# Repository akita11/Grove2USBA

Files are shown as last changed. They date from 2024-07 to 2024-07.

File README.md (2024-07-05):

# Grove2USBA

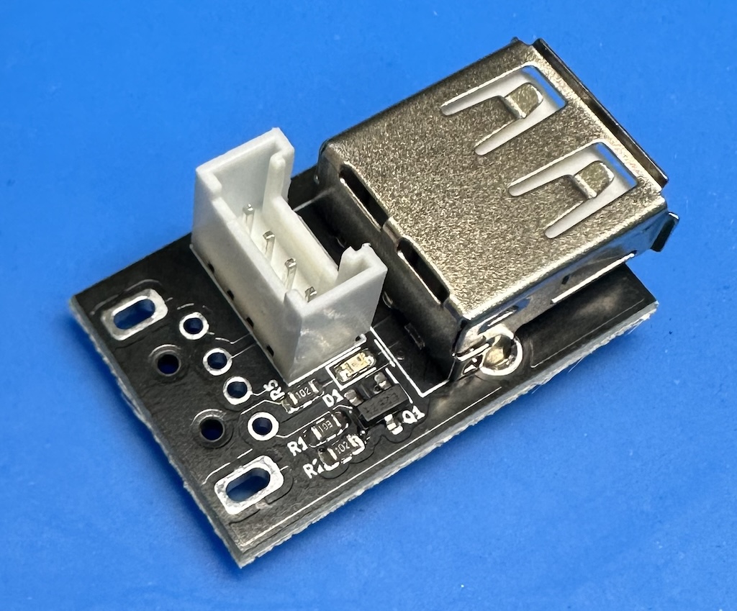
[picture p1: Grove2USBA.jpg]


Grove端子から電源(+5V)をUSB-Aコネクタ（ソケット）への給電をGrove端子の信号線で制御することができます。

## 使い方

Grove端子をM5Stack等に接続し、給電したい機器をUSB-Aコネクタに接続します。Grove端子の信号線（初期状態では"A"(2番)）を"L"にすると給電され、"H"（または開放）にすると給電されません。

給電したい機器への電力はGrove端子から受けますので、供給側の電力供給が不足する場合は、[「M5Stack USB TypeC2Grove外部電源供給ユニット」](https://www.switch-science.com/products/8453)等をつかって電源を強化してください。

## 設定の変更

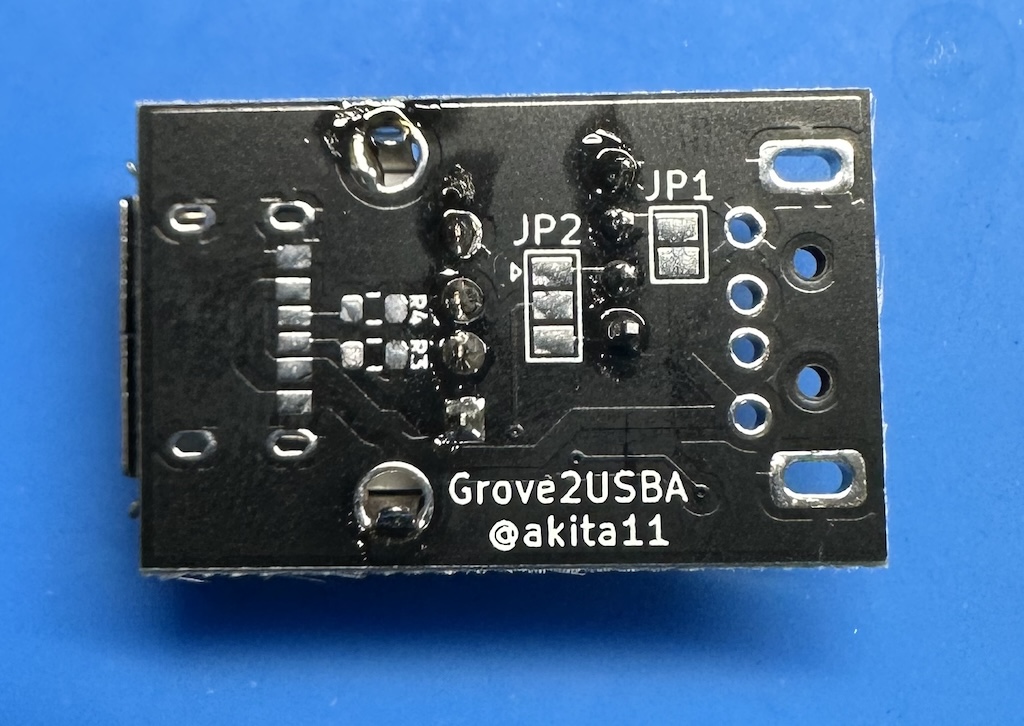
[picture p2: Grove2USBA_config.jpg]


コネクタへの給電制御をGrove端子の2本の信号線のどちらで行うかを切り替えることができます。

- A(2番): JP2を中央-△マークのある側をショート（初期状態）
- B(1番): JP2を中央-△マークのない側をショート（※中央-△マークのある側のパターンをカットしてください）

## 使い方（オプション）

給電のためのUSB-Aプラグ、またはUSB-Cコネクタを追加でとりつけ、そちらから給電することができます。
これらを使う場合は、JP1をカット（初期状態はショート）することで、Grove端子からの+5V給電を切ることができます。

- USB-Aプラグ: [秋月電子・USB-4AM103AS](https://akizukidenshi.com/catalog/g/g102236/)等
- USB-Cコネクタ: [秋月電子・UJC-HP-3-SMT-TR](https://akizukidenshi.com/catalog/g/g116438/)等＋5.1kΩチップ抵抗(0603/1608)x2個

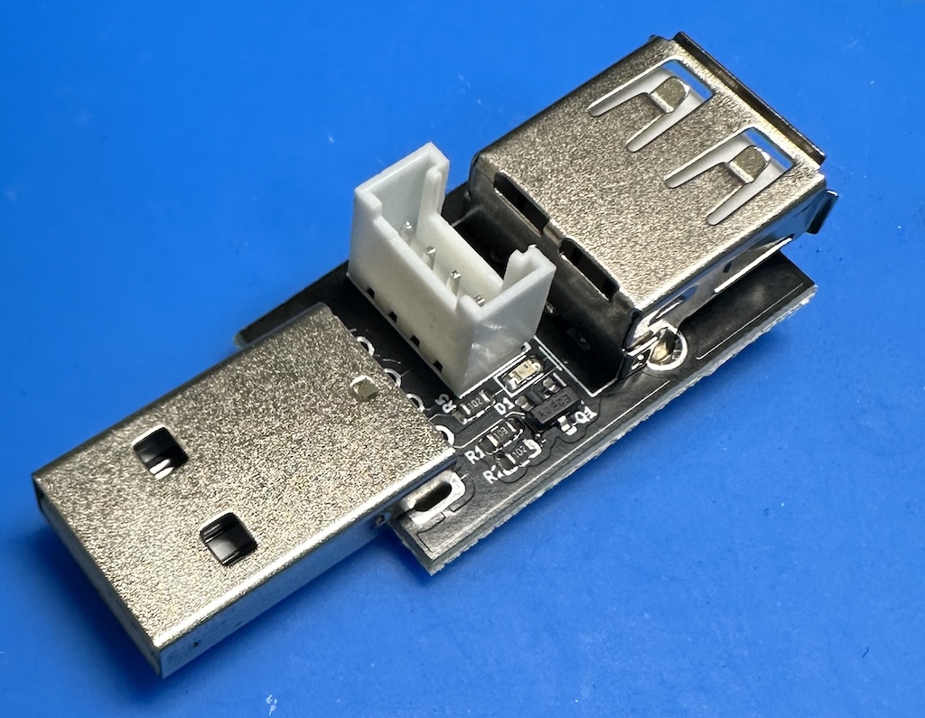
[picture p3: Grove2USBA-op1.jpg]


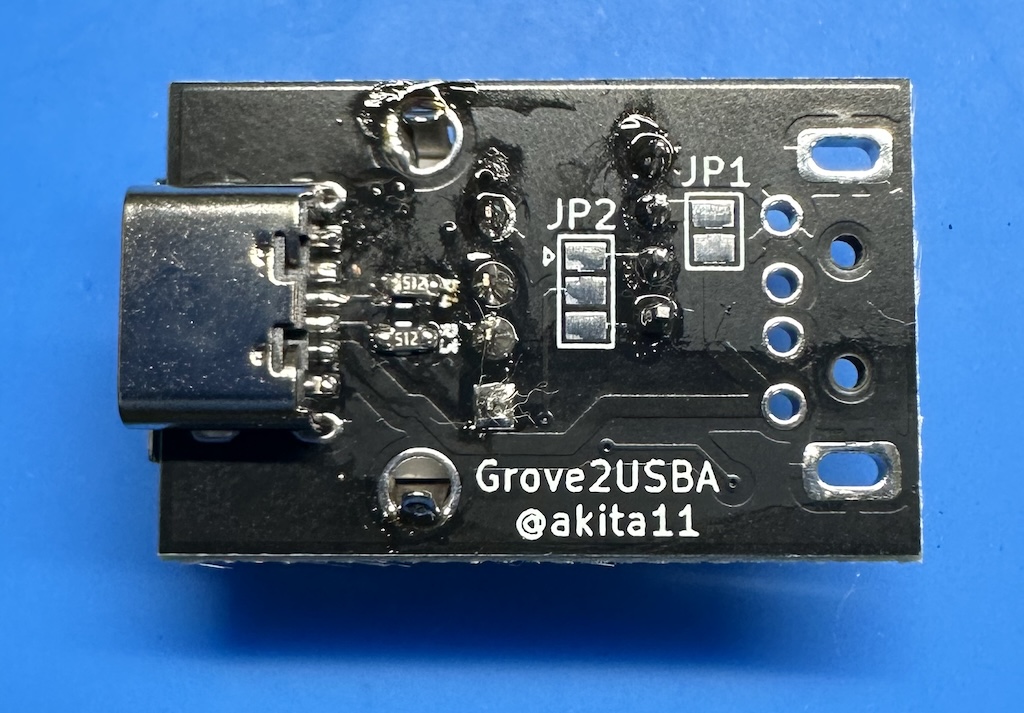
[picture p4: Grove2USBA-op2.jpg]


## Author

Junichi Akita (akita@ifdl.jp, @akita11)

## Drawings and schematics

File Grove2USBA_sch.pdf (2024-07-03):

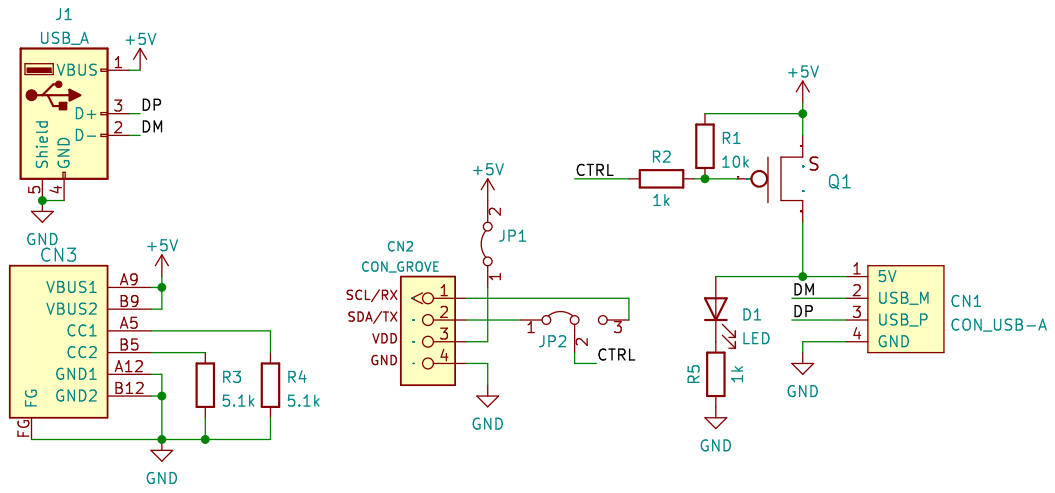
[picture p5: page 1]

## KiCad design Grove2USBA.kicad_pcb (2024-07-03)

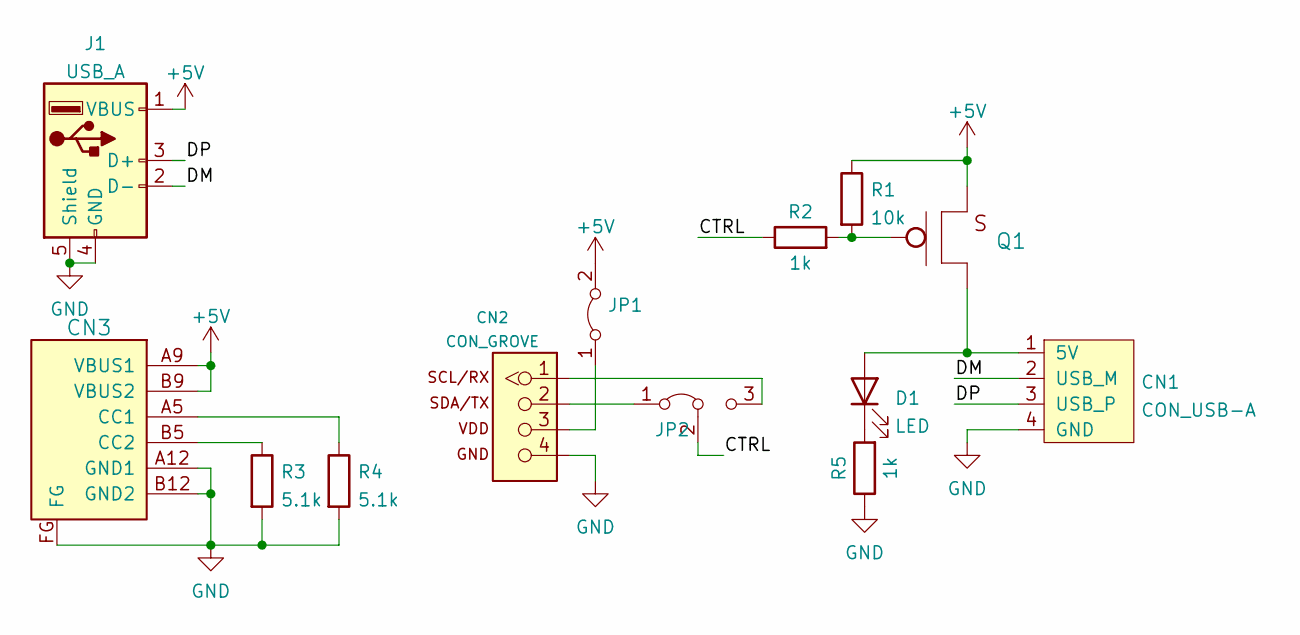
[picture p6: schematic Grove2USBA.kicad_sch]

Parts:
CN1: CON_USB-A; USB_A_Molex_67643_Horizontal
CN2: CON_GROVE; CON_GROVE_V
CN3: CON_USB-C-6; USB-C_6P
D1: LED; LED_0603_1608Metric
J1: USB_A; USB-A_plug
JP1: Jumper_2_Bridged; SolderJumper-2_P1.3mm_Bridged_Pad1.0x1.5mm
JP2: Jumper_3_Bridged12; SolderJumper-3_P1.3mm_Bridged12_Pad1.0x1.5mm
Q1: TR_PMOS_IRLML6402; SOT-23
R1: 10k; R_0603_1608Metric
R2, R5: 1k; R_0603_1608Metric
R3, R4: 5.1k; R_0603_1608Metric

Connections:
+5V: CN3.A9 (VBUS1), CN3.B9 (VBUS2), J1.1 (VBUS), JP1.2 (B), Q1.2 (S), R1.1
/CTRL: JP2.2 (C), R2.1
/DM: CN1.2 (USB_M), J1.2 (D-)
/DP: CN1.3 (USB_P), J1.3 (D+)
GND: CN1.4 (GND), CN2.4, CN3.A12 (GND1), CN3.B12 (GND2), CN3.FG, J1.4 (GND), J1.5 (Shield), R3.2, R4.2, R5.1
unnamed: CN1.1 (5V), D1.2 (A), Q1.3 (D)
unnamed: CN2.1, JP2.3 (B)
unnamed: CN2.2, JP2.1 (A)
unnamed: CN2.3, JP1.1 (A)
unnamed: CN3.A5 (CC1), R4.1
unnamed: CN3.B5 (CC2), R3.1
unnamed: D1.1 (K), R5.2
unnamed: Q1.1 (G), R1.2, R2.2

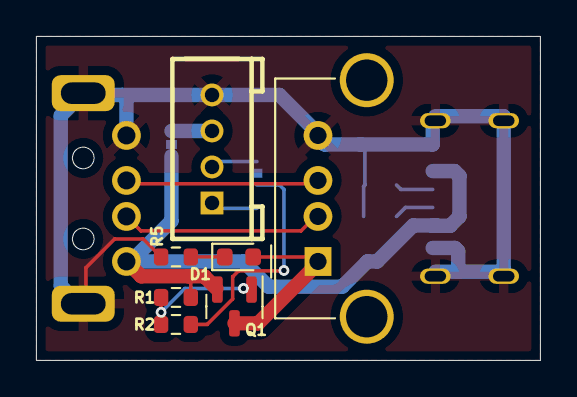
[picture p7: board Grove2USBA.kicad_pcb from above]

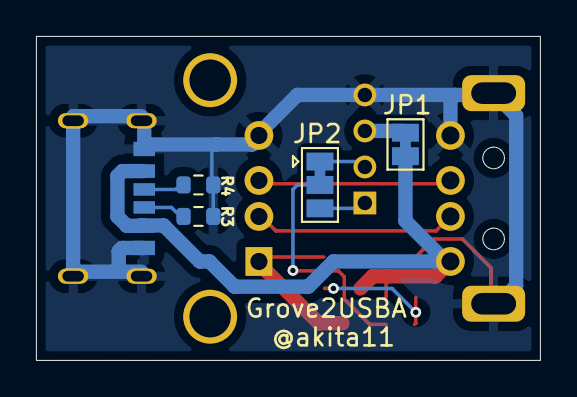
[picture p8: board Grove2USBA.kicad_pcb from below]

Board: 2 copper layers, 28.0 x 18.0 mm, 13 parts (5 on the bottom side), 13 nets.
